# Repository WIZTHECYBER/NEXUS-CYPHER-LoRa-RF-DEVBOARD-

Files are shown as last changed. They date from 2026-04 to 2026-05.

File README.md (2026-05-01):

# 🛰️ NEXUS CYPHER: RP2040 LoRa RF Devboard





Yo! Welcome to the **Nexus Cypher**. 

I designed this board, and ngl, getting it to the finish line was a massive reality check. This repo doesn't just have the final manufacturing files—it’s the actual log of every time I got humbled by the reviewers and the factory robots. If you're designing your first complex RF board, please learn from my mistakes so you don't get kicked back as much as I did.

## 💡 What I Actually Made
The Nexus Cypher is a custom, open-source Long Range (LoRa) radio frequency devboard. I wanted a flexible, overpowered platform for RF hacking and experiments. 

**The Specs:**
* **Brain:** Raspberry Pi RP2040
* **Radio:** Semtech SX1262 (LoRa)
* **RF Switch:** PE4259 (UltraCMOS SPDT)
* **Storage:** W25Q128JVS (128M-bit Flash)
* **Power:** AP2112K-3.3V LDO
* **Extras:** USB-C, 0.96" OLED header, Reset & Boot buttons.

## Schematics 


## PCB routing 




## FINAL PCB 


## 💀 The "Wall of Shame" (Dev Journal)
I spent like 16 hours hyper-focusing on impedance matching and RF traces. I thought I was a genius. Then I submitted it for review and got hit with reality. Here is everything that went wrong and how I fixed it:

### 1. Forgetting humans actually hold these boards
I was so zoomed in on the physics of the RF traces that I completely ignored the physical board itself. 
* **The Roast:** The reviewer literally told me to *"Please neaten up your board a bit with silkscreen, rounded corners, ect."*. 
* **The Fix:** I had sharp 90-degree corners that would probably slice my hand open, and I just slapped my text (`R1`, `C12`, etc.) right on top of my carefully routed traces. I had to go back into KiCad, draw smooth arcs on the `Edge.Cuts` layer, and individually move every single piece of text so the factory could actually print it.

### 2. Asking for way too much money
I was submitting this for a hardware grant and totally fumbled the math.
* **The Roast:** *"Your bom cost is unrealistic you cant be requesting this number... please resubmit with the correcct tier"*.
* **The Fix:** Bruh, you can't just guess your numbers. I had to actually calculate the real-world cost of the RP2040, the LoRa IC, and the JLCPCB assembly fees, and request the correct tier that matched reality.

### 3. Excel cooked my BOM
I thought exporting a Bill of Materials (BOM) was just a one-click thing. 
* **The Roast:** The reviewer just straight up said *"your BOM.csv is broken"*.
* **The Fix:** Excel completely mangled my CSV file. All my capacitors (`C1`, `C8`, `C9`) spilled across 10 different columns, and it used semicolons instead of commas. Also, I learned that JLCPCB factory robots don't read English—they just match text. I had to manually sanitize the entire spreadsheet so the Pick & Place machines wouldn't throw an error. 

### 4. The "Ghost" Repo
I assumed the hardware spoke for itself and left everything blank.
* **The Roast:** *"your ReadME is missing description about your project. Your journals are also not descriptive enough, you need to explain what you did what went well / wrong etc"*.
* **The Fix:** Open-source hardware is literally useless if nobody knows *why* you built it or how it works. That's exactly why I'm writing this massive README right now.

## 🗂️ Files in this Repo
* `/Nexus Cypher production/` - The actual KiCad 9.0 source files.
* `Nexus cypher gerber.zip` - Production-ready Gerbers.
* `Nexus Cypher BOM.csv` - The sanitized, robot-approved Bill of Materials.
* `Nexus Cypher-all-pos.csv` - Pick & Place (CPL) file.

## ⚖️ License
This is open-source hardware, fr. 

* **Hardware:** Released under the **CERN Open Hardware Licence Version 2 - Strongly Reciprocal (CERN-OHL-S)**. You can use it, mod it, and fab it, but if you change it, you gotta share it under the same terms.
* **Docs/Software:** Released under the **MIT License**.

---
*Built by WIZTHECYBER.*

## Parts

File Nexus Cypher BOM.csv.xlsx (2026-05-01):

COMPONENTS | Footprints | Quantity | Designation AND VALUES | DESIGNATORS
1;AE111 | U.FL_Hirose_U.FL-R-SMT-1_Vertica | 1 | ANTENNA | AE111
2;"spst switch" | SW_SPST_B3U-1000P | 1 | boot button | BOOT
3;"Capacitor 1, 8, 9, 13, 14, 17, 18, 19, 20, 21, 22" | C_0603_1608Metric | 11 | 100nF Capacitors | C1, C8, C9, C13, C14, C17, C18, C19, C20, C21, C22
4;"Capacitor 2" | C_0603_1608Metric | 1 | 1nF Capacitor | C2
5;"Capacitor 3" | C_0603_1608Metric | 1 | 39pF Ca[acitor | C3
6;"Capacitor 4 , 5 | C_0603_1608Metric | 2 | 3.3pF Capacitor | C4 , C5
7;"Capacitor 6" | C_0603_1608Metric | 1 | 47pF Capacitor | C6
8;"Capacitor 7" | C_0603_1608Metric | 1 | 47nF Capacitor | C7
9;"Capacitor 10" | C_0603_1608Metric | 1 | 470nF Capacitor | C10
10;"Capacitor 11 , 12" | C_0603_1608Metric | 2 | 27pF Capacitor | C11 , C12
11;"Capacitor 15, 16" | C_0603_1608Metric | 2 | 1uF Capacitor | C15 , C16
12;"Capacitor 23" | C_0603_1608Metric | 1 | 100nF Capacitors | C23
13;"Capacitor 24,25 | C_0805_2012Metric | 2 | 10uF Capacitor | C24 , C25
14;"FL1" | Balun_Johanson_0900FM15K0039 | 1 | 0900FM15K0039 | FL1
15;"0.96 oled display" | PinSocket_1x04_P2.54mm_Vertical | 1 | Conn_01x04_Socket | J3
16;"L1 inductor 47nH" | L_0603_1608Metric | 1 | 47nH inductor | L1
17;"L2 inductor 9.1nH" | L_0603_1608Metric | 1 | 9.1nH inductor | L2
18;"L3 Inductor 15uH" | L_0805_2012Metric | 1 | 15uH inductor | L3
19;"LED blue colour " | LED_0603_1608Metric | 1 | blue LED | LED1
20;"R1" | R_0603_1608Metric | 1 | 100 ohm | R1
21;"R1K,R3 | R_0603_1608Metric | 3 | 1K ohm | R1K,R3
22;"R4,10 | R_0603_1608Metric | 2 | 10K ohm | R4 , R10
23;"R5 , 6 | R_0603_1608Metric | 2 | 5.1K ohm | R5 ,R6
24;"R8.9 | R_0603_1608Metric | 2 | 27 ohm | R8 ,R9
25;"R11,12 | R_0603_1608Metric | 2 | 4.7K ohm | R11 ,R12
26;"spdt switch " | SW_SPST_B3U-1000P | 1 | Reset button | RESET
27;"U1 RP2040" | QFN-56-1EP_7x7mm_P0.4mm_EP3.2x3.2mm | 1 | RP2040 | U1
28;"U2 SX1262IMLTRT" | QFN-24-1EP_4x4mm_P0.5mm_EP2.6x2.6mm | 1 | SX1262IMLTRT | U2
29;"U3 W25Q128JVS" | SOIC-8_5.3x5.3mm_P1.27mm | 1 | W25Q128JVS | U3
30;"U4 "PE4259" | SOT-363_SC-70-6 | 1 | PE4259 | U4
31;"U5 AP2112K-3.3" | SOT-23-5 | 1 | AP2112K-3.3 | U5
32;"USB-C_Receptacle_USB2.0_16P" | USB_C_Receptacle_HRO_TYPE-C-31-M-12 | 1 | USB-C_Receptacle_USB2.0_16P | USB_C
33;"Y1 CRYSTAL 32MHz" | Crystal_SMD_3225-4Pin_3.2x2.5mm_HandSoldering | 1 | CRYSTAL 32MHz | Y1
34;"Y2 CRYSTAL 12mHZ" | Crystal_SMD_3225-4Pin_3.2x2.5mm_HandSoldering | 1 | CRYSTAL 12MHz | Y2

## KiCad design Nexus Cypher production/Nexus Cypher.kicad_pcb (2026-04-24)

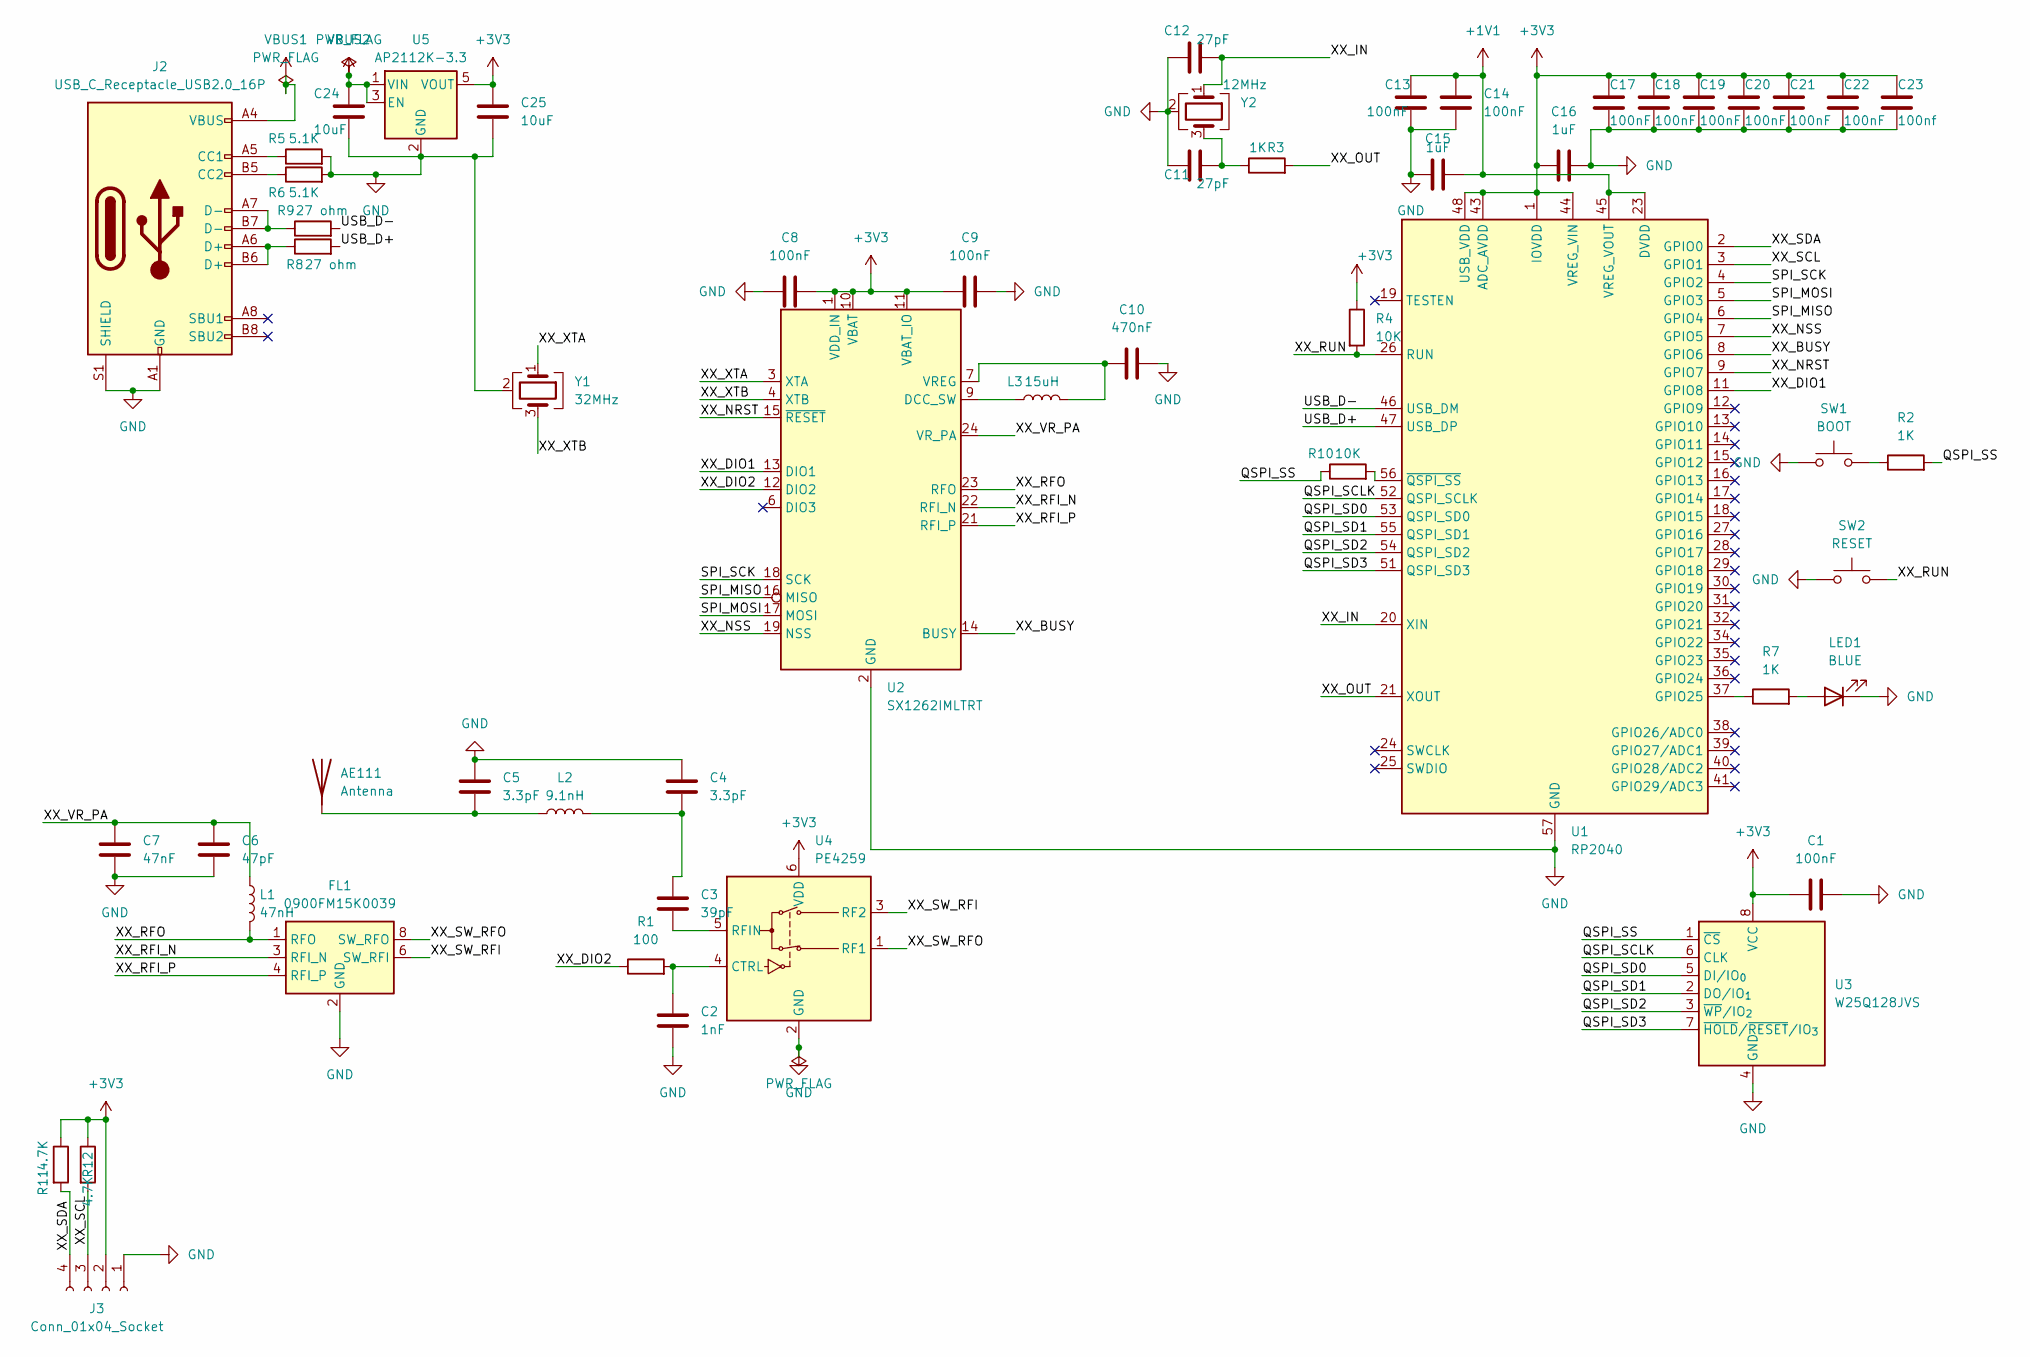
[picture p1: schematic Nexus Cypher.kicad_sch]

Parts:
AE111: Antenna; U.FL_Hirose_U.FL-R-SMT-1_Vertical
C1, C8, C9, C13, C14, C17, C18, C19, C20, C21, C22: 100nF; C_0603_1608Metric
C2: 1nF; C_0603_1608Metric
C3: 39pF; C_0603_1608Metric
C4, C5: 3.3pF; C_0603_1608Metric
C6: 47pF; C_0603_1608Metric
C7: 47nF; C_0603_1608Metric
C10: 470nF; C_0603_1608Metric
C11, C12: 27pF; C_0603_1608Metric
C15, C16: 1uF; C_0603_1608Metric
C23: 100nf; C_0603_1608Metric
C24, C25: 10uF; C_0805_2012Metric
FL1: 0900FM15K0039; Balun_Johanson_0900FM15K0039
J2: USB_C_Receptacle_USB2.0_16P; USB_C_Receptacle_HRO_TYPE-C-31-M-12
J3: Conn_01x04_Socket; PinSocket_1x04_P2.54mm_Vertical
L1: 47nH; L_0603_1608Metric
L2: 9.1nH; L_0603_1608Metric
L3: 15uH; L_0805_2012Metric
LED1: BLUE; LED_0603_1608Metric
R1: 100; R_0603_1608Metric
R2, R3, R7: 1K; R_0603_1608Metric
R4, R10: 10K; R_0603_1608Metric
R5, R6: 5.1K; R_0603_1608Metric
R8, R9: 27 ohm; R_0603_1608Metric
R11, R12: 4.7K; R_0603_1608Metric
SW1: BOOT; SW_SPST_B3U-1000P
SW2: RESET; SW_SPST_B3U-1000P
U1: RP2040; QFN-56-1EP_7x7mm_P0.4mm_EP3.2x3.2mm
U2: SX1262IMLTRT; QFN-24-1EP_4x4mm_P0.5mm_EP2.6x2.6mm
U3: W25Q128JVS; SOIC-8_5.3x5.3mm_P1.27mm
U4: PE4259; SOT-363_SC-70-6
U5: AP2112K-3.3; SOT-23-5
Y1: 32MHz; Crystal_SMD_3225-4Pin_3.2x2.5mm_HandSoldering
Y2: 12MHz; Crystal_SMD_3225-4Pin_3.2x2.5mm_HandSoldering

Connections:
+1V1: C13.1, C14.1, C15.2, U1.23 (DVDD), U1.45 (VREG_VOUT), U1.50 (DVDD)
+3V3: C1.1, C8.2, C9.1, C16.1, C17.1, C18.1, C19.1, C20.1, C21.1, C22.1, C23.1, C25.1, J3.2, R4.1, R11.1, R12.1, U1.1 (IOVDD), U1.10 (IOVDD), U1.22 (IOVDD), U1.33 (IOVDD), U1.42 (IOVDD), U1.43 (ADC_AVDD), U1.44 (VREG_VIN), U1.48 (USB_VDD), U1.49 (IOVDD), U2.1 (VDD_IN), U2.10 (VBAT), U2.11 (VBAT_IO), U3.8 (VCC), U4.6 (VDD), U5.5 (VOUT)
/QSPI_SCLK: U1.52 (QSPI_SCLK), U3.6 (CLK)
/QSPI_SD0: U1.53 (QSPI_SD0), U3.5 (DI/IO_{0})
/QSPI_SD1: U1.55 (QSPI_SD1), U3.2 (DO/IO_{1})
/QSPI_SD2: U1.54 (QSPI_SD2), U3.3 (~WP/IO_{2})
/QSPI_SD3: U1.51 (QSPI_SD3), U3.7 (~HOLD/~RESET/IO_{3})
/QSPI_SS: R2.2, R10.1, U3.1 (~CS); also elsewhere on the board
/SPI_MISO: U1.6 (GPIO4), U2.16 (MISO)
/SPI_MOSI: U1.5 (GPIO3), U2.17 (MOSI)
/SPI_SCK: U1.4 (GPIO2), U2.18 (SCK)
/USB_D+: R8.2, U1.47 (USB_DP)
/USB_D-: R9.2, U1.46 (USB_DM)
/XX_BUSY: U1.8 (GPIO6), U2.14 (BUSY)
/XX_DIO1: U1.11 (GPIO8), U2.13 (DIO1)
/XX_DIO2: R1.1, U2.12 (DIO2)
/XX_IN: C12.2, U1.20 (XIN), Y2.1
/XX_NRST: U1.9 (GPIO7), U2.15 (~RESET)
/XX_NSS: U1.7 (GPIO5), U2.19 (NSS)
/XX_OUT: R3.2, U1.21 (XOUT)
/XX_RFI_N: FL1.3 (RFI_N), U2.22 (RFI_N)
/XX_RFI_P: FL1.4 (RFI_P), U2.21 (RFI_P)
/XX_RFO: FL1.1 (RFO), L1.2, U2.23 (RFO)
/XX_RUN: R4.2, SW2.2, U1.26 (RUN); also elsewhere on the board
/XX_SCL: J3.3, R12.2, U1.3 (GPIO1)
/XX_SDA: J3.4, R11.2, U1.2 (GPIO0)
/XX_SW_RFI: FL1.6 (SW_RFI), U4.3 (RF2)
/XX_SW_RFO: FL1.8 (SW_RFO), U4.1 (RF1)
/XX_VR_PA: C6.1, C7.1, L1.1, U2.24 (VR_PA)
/XX_XTA: U2.3 (XTA), Y1.1
/XX_XTB: U2.4 (XTB), Y1.3
GND: C1.2, C2.2, C4.2, C5.2, C6.2, C7.2, C8.1, C9.2, C10.2, C11.2, C12.1, C13.2, C14.2, C15.1, C16.2, C17.2, C18.2, C19.2, C20.2, C21.2, C22.2, C23.2, C24.2, C25.2, FL1.2 (GND), FL1.5 (GND), FL1.7 (GND), FL1.9 (GND), FL1.10 (GND), J2.A1 (GND), J2.A12 (GND), J2.B1 (GND), J2.B12 (GND), J2.S1 (SHIELD), J3.1, LED1.1 (K), R5.2, R6.2, SW1.1, SW2.1, U1.57 (GND), U2.2 (GND), U2.5 (GND), U2.8 (GND), U2.20 (GND), U2.25 (GND), U3.4 (GND), U4.2 (GND), U5.2 (GND), Y1.2 (G), Y1.4 (G), Y2.2 (G), Y2.4 (G); also elsewhere on the board
unnamed: AE111.1 (A_1), C5.1, L2.1
unnamed: C3.1, C4.1, L2.2
unnamed: C11.1, R3.1, Y2.3
unnamed 35: J2.A5 (CC1), R5.1; also elsewhere on the board
unnamed 36: J2.B5 (CC2), R6.1; also elsewhere on the board
unnamed 37: J2.A6 (D+), J2.B6 (D+), R8.1; also elsewhere on the board
unnamed 38: J2.A7 (D-), J2.B7 (D-), R9.1; also elsewhere on the board
unnamed: J2.A4 (VBUS), J2.A9 (VBUS), J2.B4 (VBUS), J2.B9 (VBUS)
unnamed: LED1.2 (A), R7.2
unnamed 41: R2.1, SW1.2; also elsewhere on the board
unnamed: R7.1, U1.37 (GPIO25)
unnamed: R10.2, U1.56 (~QSPI_SS)
unnamed: L3.1, U2.9 (DCC_SW)
unnamed: C10.1, L3.2, U2.7 (VREG)
unnamed: C2.1, R1.2, U4.4 (CTRL)
unnamed: C3.2, U4.5 (RFIN)
VBUS2: C24.1, U5.1 (VIN), U5.3 (EN)

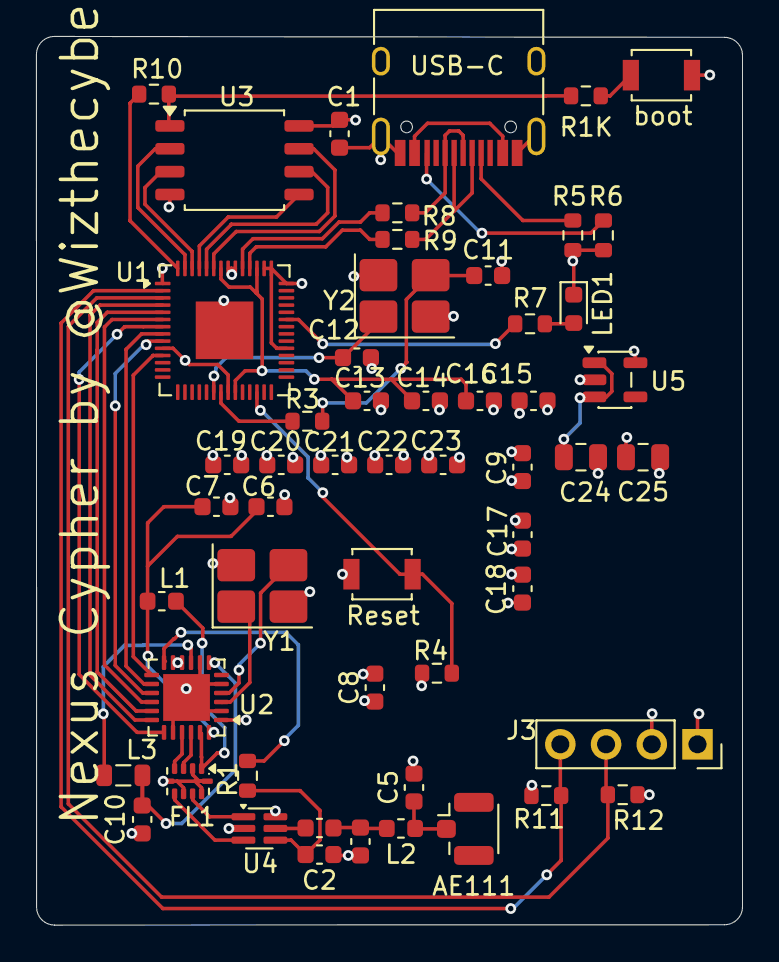
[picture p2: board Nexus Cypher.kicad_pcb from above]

Board: 4 copper layers, 39.2 x 49.4 mm, 54 parts (0 on the bottom side), 49 nets.

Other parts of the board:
R1K: 1K; R_0603_1608Metric
Reset: RESET; SW_SPST_B3U-1000P
USB-C: USB_C_Receptacle_USB2.0_16P; USB_C_Receptacle_HRO_TYPE-C-31-M-12
boot: BOOT; SW_SPST_B3U-1000P

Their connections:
/QSPI_SS: R1K.2; also elsewhere on the board
/XX_RUN: Reset.2; also elsewhere on the board
GND: Reset.1, USB-C.A1 (GND), USB-C.A12 (GND), USB-C.B1 (GND), USB-C.B12 (GND), USB-C.S1 (SHIELD), boot.1; also elsewhere on the board
unnamed 35: USB-C.A5 (CC1); also elsewhere on the board
unnamed 36: USB-C.B5 (CC2); also elsewhere on the board
unnamed 37: USB-C.A6 (D+), USB-C.B6 (D+); also elsewhere on the board
unnamed 38: USB-C.A7 (D-), USB-C.B7 (D-); also elsewhere on the board
unnamed 41: R1K.1, boot.2; also elsewhere on the board
VBUS1: USB-C.A4 (VBUS), USB-C.A9 (VBUS), USB-C.B4 (VBUS), USB-C.B9 (VBUS)
